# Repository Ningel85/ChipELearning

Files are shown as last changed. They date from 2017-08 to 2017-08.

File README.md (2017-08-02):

# ChipELearning
Projet ChipELearning

* Download & Install Arduino IDE: https://www.arduino.cc/en/Main/Software 
* Download & Install Teensy Driver : https://www.pjrc.com/teensy/td_download.html
* Copy all libraries to C:\Users\user\Documents\Arduino\libraries (or wherever your library folder is installed)
* Arduino IDE : "Board: Teensy 3.2" 

ChipELearning is a robot able to learn movements, which makes every ChipELearning unique !

Bill of material :
* 1 x [Teensy 3.2](http://www.francerobotique.com/electronique/457-module-teensy-32.html) 
* 1 x Teensy Shield	
* 1 x [Maestro Micro](http://www.francerobotique.com/contr%C3%B4leurs-interfaces/138-contr%C3%B4leur-usb-micro-maestro-6.html)	
* 2 x [Servomotor FeedBack Small](https://www.adafruit.com/product/1449)	
* 4 x [Servomotor FeedBack Medium](https://www.adafruit.com/product/1404)
* 1 x [Accelerometer LSM303D](http://www.francerobotique.com/orientation/244-acc%C3%A9l%C3%A9rom%C3%A8tre-3d-lsm303d.html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)	
* 1 x [IR sensor TSOP38238](http://www.francerobotique.com/luminosit%C3%A9-couleur/420-r%C3%A9cepteur-ir-tsop38238.html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)	
* 1 x [Remote control](http://www.francerobotique.com/t%C3%A9l%C3%A9commande/426-mini-t%C3%A9l%C3%A9commande.html)	
* 1 x [I2C display 128x32](https://www.adafruit.com/product/931)	
* 1 x [Regulator step-down 5V/3A](https://www.adafruit.com/product/1385)	
* 2 x [Battery 1S](http://www.francerobotique.com/batterie/302-batterie-li-ion-37v-1300mah-lb-040.html)	
* 2 x [Battery Charger](http://www.francerobotique.com/chargeur/303-chargeur-de-batterie-li-ion-lbb-040.html)

- The Teensy controller has various I/Os : I²C, UART, CAN, Touch, ADC, PWM.
It has an EEPROM big enough for the robot and is smaller than Arduino Uno and Arduino Mega.
- The Infrared sensor allows me to control the robot with a remote controller.
- The display is small but still has a decent resolution to write text and display drawings, logos, etc. Wiring the display is very simple as it uses an I²C bus to communicate.
- Touch I/Os from the Teensy board allows me to interact with the robot without the use of a push button. On ChipELearning, there is a paper fastener but anything else that conducts electricity is suitable.
- Servomotors send back their position, which allows the robot to memorize sequences of movements and play them back indefinitely.
- The accelerometer is used for the "Balance" mode. But it could also detect when it's falling or if it is upside down.
- The robot is powered by 2 Robotis batteries made of one cell each, connected in series. They could be replaced by any power supply up to 16V.
A power adapter allows to generate a 5V supply for the Teensy controller and the servos.

Functionalities :
- Remote Controller :
ChipELearning can be controlled using a remote controller.
- Walking/Motions :
The robot can move forwards, backwards and can rotate. 3 sequences of movements are predefined, and binded to keys 1, 2 and 3.
- Motion learning :
Motion learning allows the robot to do anything. Jumping, Skateboarding, etc. This feature makes any robot unique.
- Balance :
The robot keeps it's balance on it's foot.

Programme TeensyChipE V1.0  TeensyChipE.ino

=================================================================
==============================================================================

ChipELearning est un robot capable d'apprendre des mouvements ce qui rend chaque ChipELearning unique! 

Bill of material :
* 1 x [Teensy 3.2](http://www.francerobotique.com/electronique/457-module-teensy-32.html) 
* 1 x Teensy Shield	
* 1 x [Maestro Micro](http://www.francerobotique.com/contr%C3%B4leurs-interfaces/138-contr%C3%B4leur-usb-micro-maestro-6.html)	
* 2 x [Servomotor FeedBack Small](https://www.adafruit.com/product/1449)	
* 4 x [Servomotor FeedBack Medium](https://www.adafruit.com/product/1404)
* 1 x [Accelerometer LSM303D](http://www.francerobotique.com/orientation/244-acc%C3%A9l%C3%A9rom%C3%A8tre-3d-lsm303d.html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)	
* 1 x [IR sensor TSOP38238](http://www.francerobotique.com/luminosit%C3%A9-couleur/420-r%C3%A9cepteur-ir-tsop38238.html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)	
* 1 x [Remote control](http://www.francerobotique.com/t%C3%A9l%C3%A9commande/426-mini-t%C3%A9l%C3%A9commande.html)	
* 1 x [I2C display 128x32](https://www.adafruit.com/product/931)	
* 1 x [Regulator step-down 5V/3A](https://www.adafruit.com/product/1385)	
* 2 x [Battery 1S](http://www.francerobotique.com/batterie/302-batterie-li-ion-37v-1300mah-lb-040.html)	
* 2 x [Battery Charger](http://www.francerobotique.com/chargeur/303-chargeur-de-batterie-li-ion-lbb-040.html)

- Le contrôleur Teensy possède des entrées sorties très variées, I2C, UART, CAN, Touch, ADC, PWM, possède une EEPROM suffisante pour le robot et est plus petite que les arduino uno et mega.
- Le capteur Infrarouge me permet de contrôler le robot avec une télécommande
- L'afficheur est petit mais a une bonne résolution pour écrire beaucoup de texte et afficher des dessins, logos... Le câblage est simple et le module communique en I2C, ce qui est très facile à utiliser
- Les I/O touch de la carte Teensy me permet d’interagir avec le robot sans bouton poussoir. Sur ChipELearning, il y a une attache parisienne mais on peut y mettre tout type d'objet conducteur. 
- Le feedback des servomoteurs retourne leur information de position. Cette option permet au robot de mémoriser les séquences de mouvement pour les refaire indéfiniment.
- L'accéléromètre est utilisé pour le mode équilibre. Mais il pourrait aussi savoir si il tombe, si il est à l'envers...
- Le robot est alimenté par 2 batteries Robotis d'une cellule chacune. Elles sont branchées en série. Un régulateur permet d'abaisser la tension à 5V pour le contrôleur Teensy et les servomoteurs. On peut y connecter une batterie de 16V maximum.

Fonctionnalités:
- Télécommande
ChipELearning peut-être contrôlé grâce à une télécommande. Avec les flèches directionnelles, des modes de jeux et d'apprentissage ainsi que 9 mouvements.
- Déplacement/Mouvement
Le robot peut se déplacer en avant, en arrière et tourner sur lui même. 3 séquences de mouvements sont pré-enregistrées et associées aux touches 1, 2 et 3.
- Apprentissage de mouvement
L'apprentissage des mouvements permet au robot de réaliser n'importe quelle action. Sauter, Faire du skate... Cette fonction rend le robot unique!
- Équilibre
Le robot reste en équilibre sur son pied. Exemple d'utilisation de l'accéléromètre

Programme TeensyChipE V1.0  TeensyChipE.ino

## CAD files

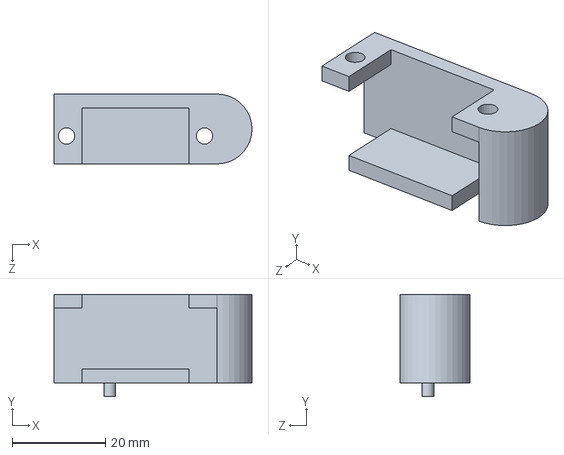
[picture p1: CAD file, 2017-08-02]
ChipE3D/MainG.SLDPRT
42.5 x 22.0 x 15.0 mm

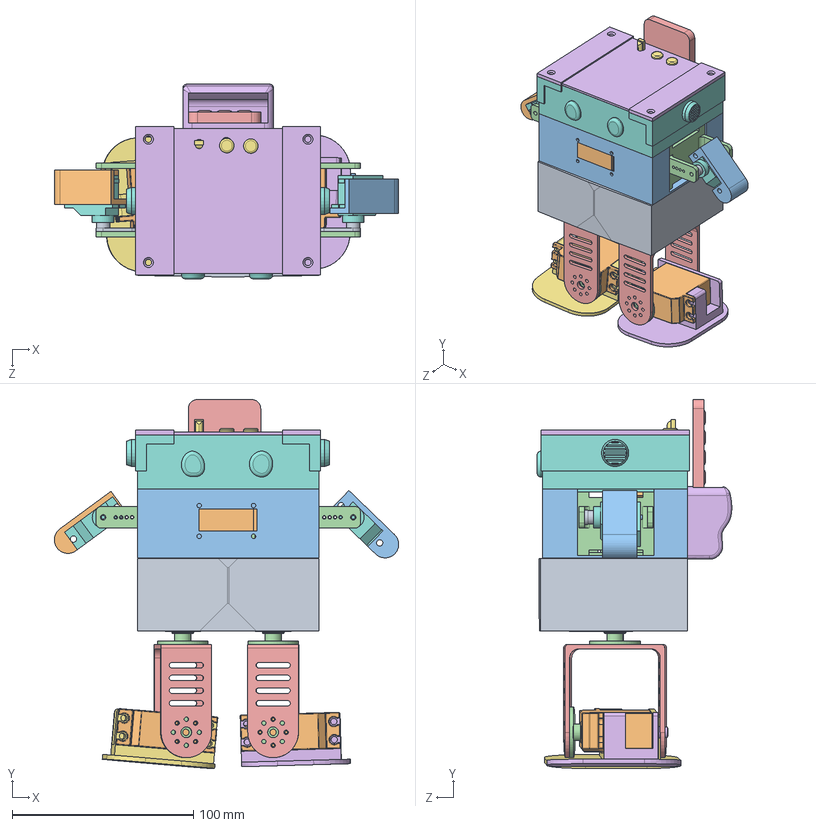
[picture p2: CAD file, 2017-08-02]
ChipE3D/Assemblage1.SLDASM
190.0 x 203.6 x 107.4 mm
BodyBase
ServoS1213 x 4
LSM303D
PalonnierS1213 x 4
Bracket x 2
Pied
Pied - Copie
BodyMiddle
SocleBat x 2
Ecran
BodyTop
Teensy-bras-corps-base-X4
PololuMicroMeastro
Couvercle
AttacheP x 2
ServoS1123 x 2
PalonnierS1123 x 2
MainD
MainG
epaule x 2
telecommande
sac
ReceptIR

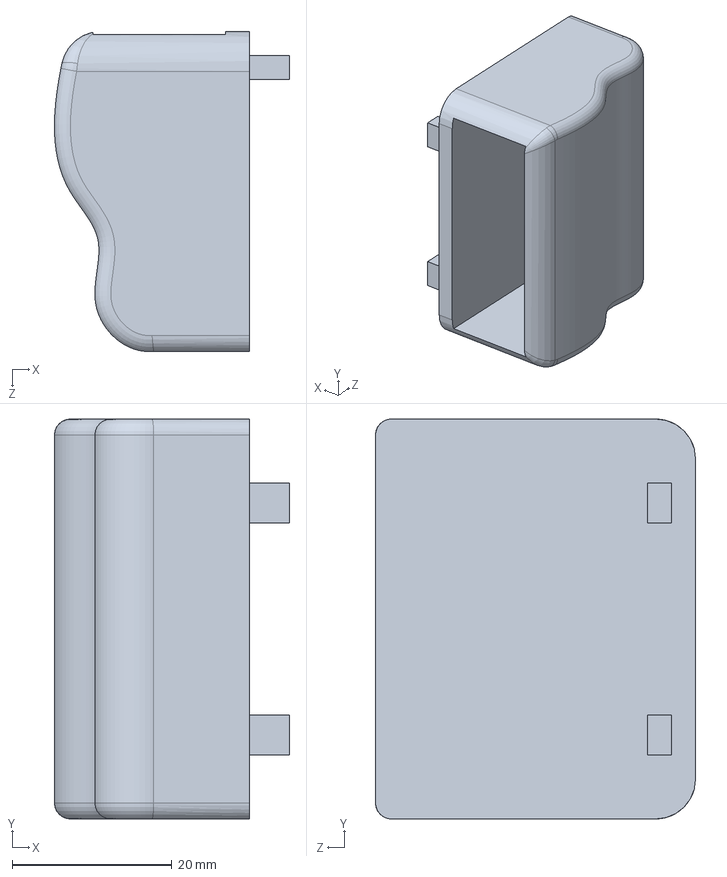
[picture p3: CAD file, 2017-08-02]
ChipE3D/sac.SLDPRT
29.4 x 50.0 x 40.0 mm

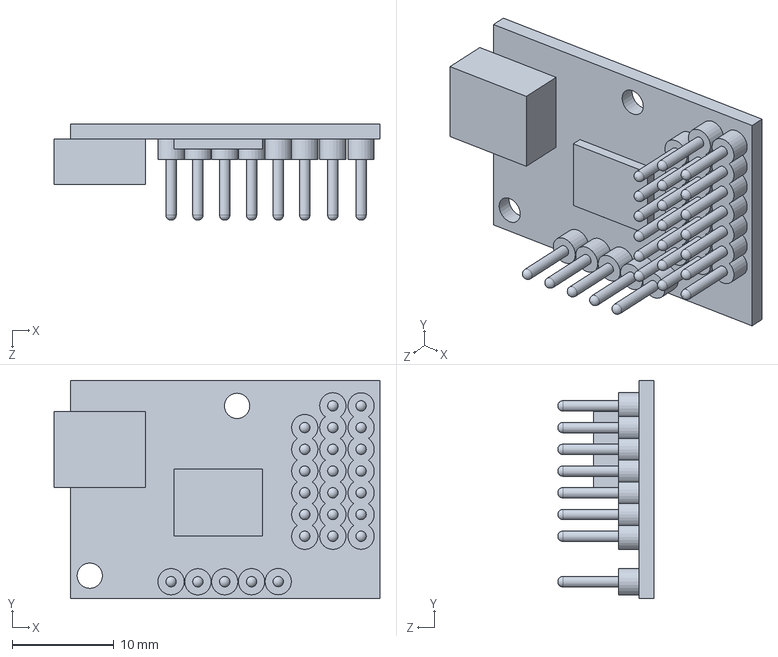
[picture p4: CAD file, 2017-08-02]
ChipE3D/PololuMicroMeastro.SLDPRT
32.1 x 21.5 x 9.50 mm

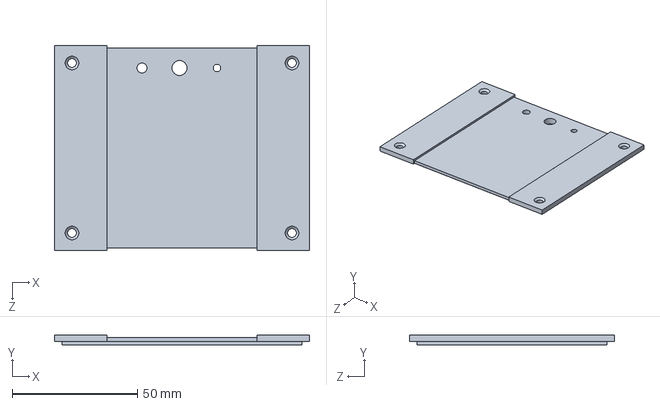
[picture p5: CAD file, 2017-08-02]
ChipE3D/Couvercle.SLDPRT
102.0 x 4.00 x 82.0 mm

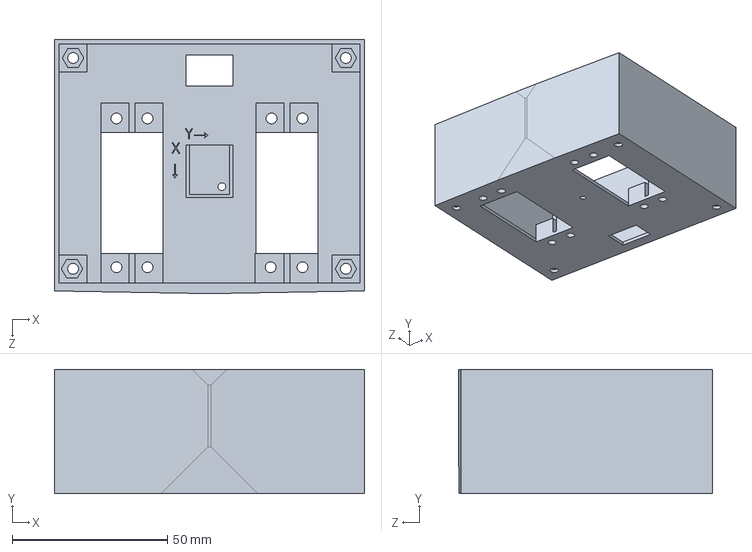
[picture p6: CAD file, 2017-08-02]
ChipE3D/BodyBase.SLDPRT
100.0 x 40.0 x 82.0 mm

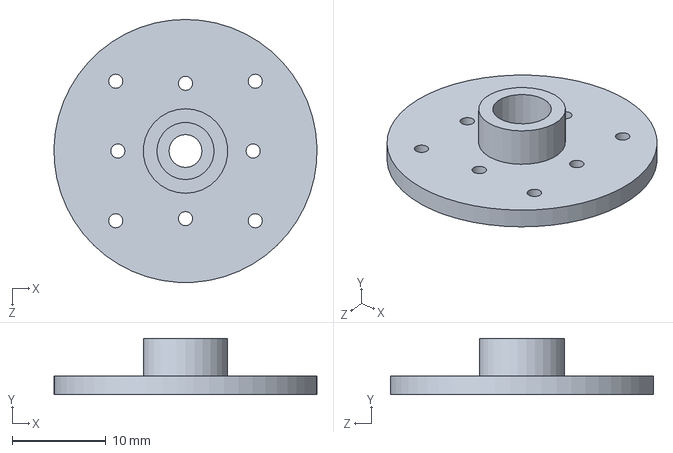
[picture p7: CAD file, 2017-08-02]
ChipE3D/PalonnierS1213.SLDPRT
28.0 x 6.00 x 28.0 mm

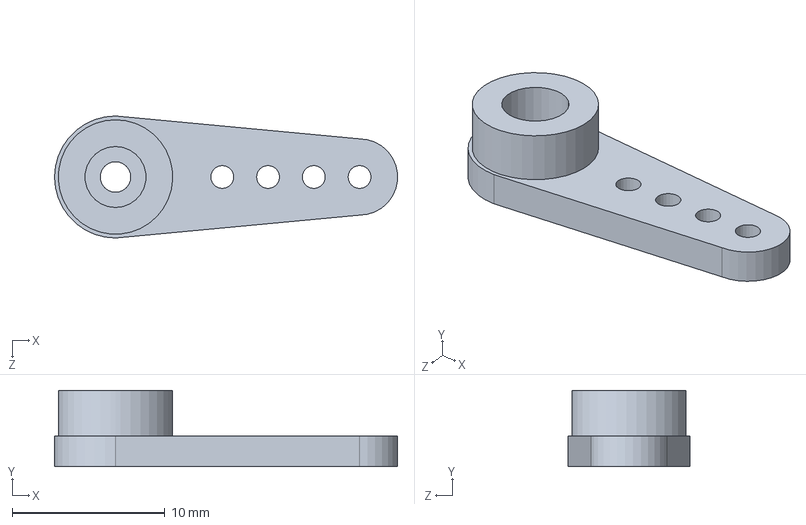
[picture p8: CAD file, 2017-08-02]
ChipE3D/PalonnierS1123.SLDPRT
22.5 x 5.00 x 8.00 mm

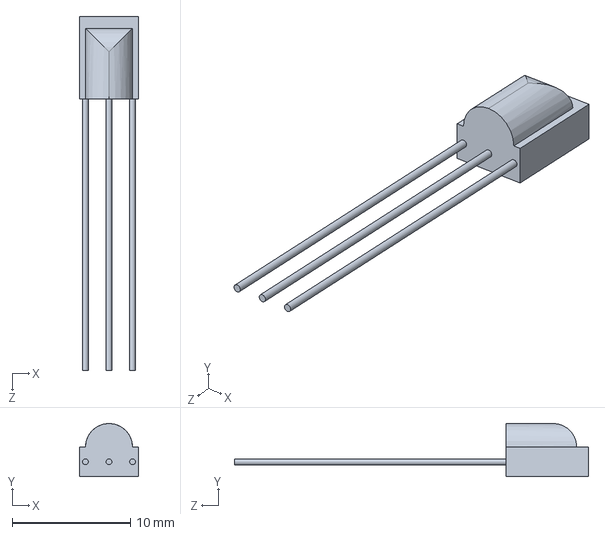
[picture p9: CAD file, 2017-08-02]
ChipE3D/ReceptIR.SLDPRT
5.00 x 4.50 x 30.0 mm

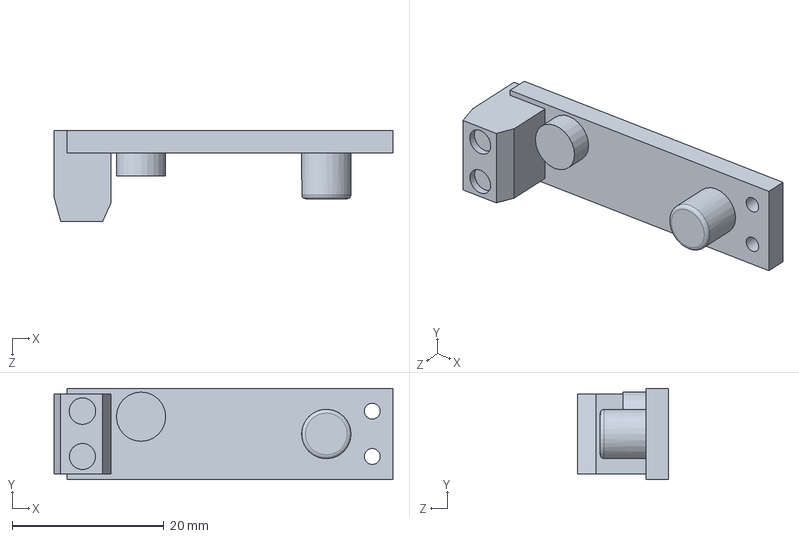
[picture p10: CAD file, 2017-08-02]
ChipE3D/Reg5VPololu3-5A.SLDPRT
44.7 x 12.0 x 12.0 mm

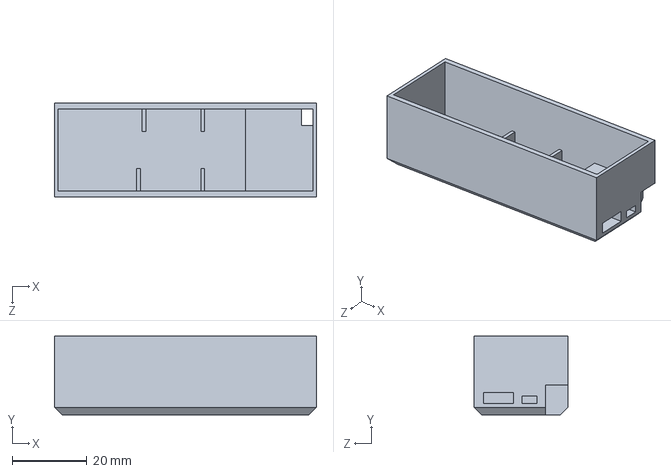
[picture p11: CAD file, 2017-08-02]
ChipE3D/SocleBat.SLDPRT
70.0 x 21.0 x 25.0 mm

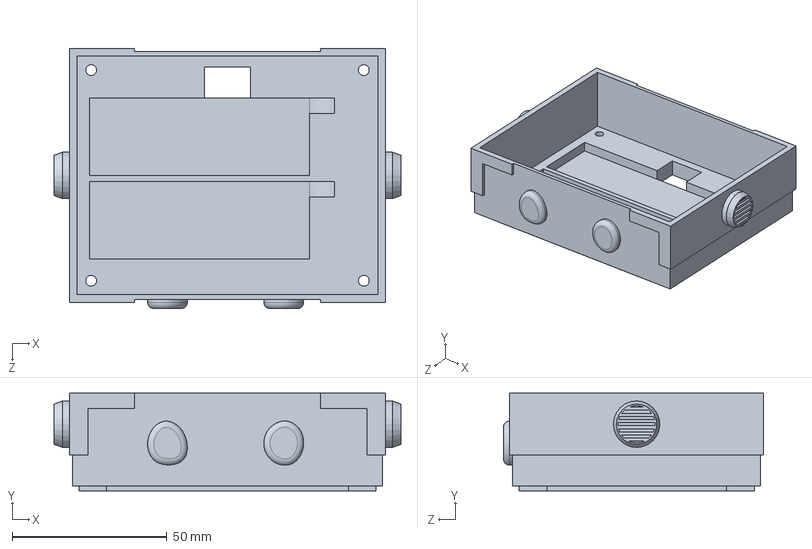
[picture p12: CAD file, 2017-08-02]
ChipE3D/BodyMiddle.SLDPRT
112.0 x 31.5 x 84.0 mm

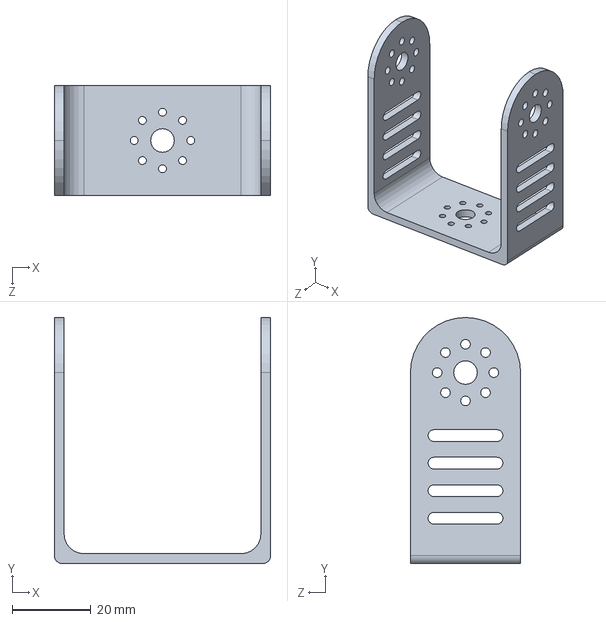
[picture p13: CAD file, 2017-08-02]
ChipE3D/Bracket.SLDPRT
55.0 x 62.5 x 28.0 mm

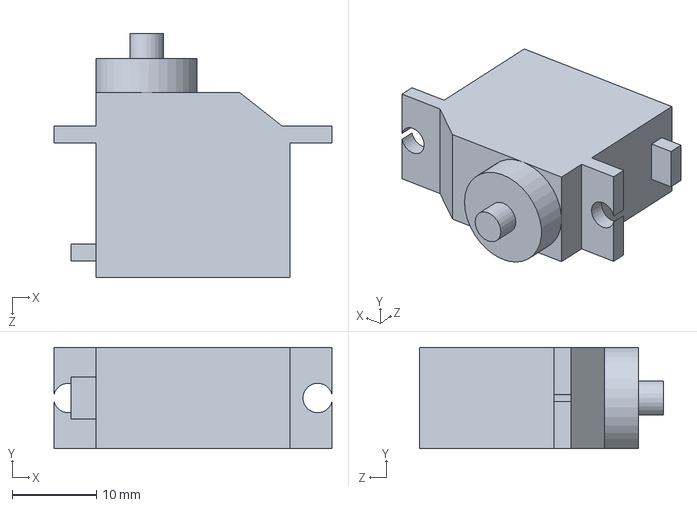
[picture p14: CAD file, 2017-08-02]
ChipE3D/ServoS1123.SLDPRT
33.0 x 12.0 x 29.0 mm

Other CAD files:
ChipE3D/MainD.SLDPRT
ChipE3D/AttacheP.SLDPRT
ChipE3D/LSM303D.SLDPRT
ChipE3D/Pied.SLDPRT
ChipE3D/BodyBase.STL
ChipE3D/BodyMiddle.STL
ChipE3D/BodyTop.SLDPRT
ChipE3D/BodyTop.STL
ChipE3D/Bracket.STL
ChipE3D/Couvercle.STL
ChipE3D/Ecran.SLDPRT
ChipE3D/MainD.STL
ChipE3D/MainG.STL
ChipE3D/Pied - Copie.SLDPRT
ChipE3D/Pied - Copie.STL
ChipE3D/Pied.STL
ChipE3D/ServoS1213.SLDPRT
ChipE3D/Teensy-bras-corps-base-X4.SLDPRT
ChipE3D/epaule.SLDPRT
ChipE3D/epaule.STL
ChipE3D/sac.STL
ChipE3D/telecommande.SLDPRT

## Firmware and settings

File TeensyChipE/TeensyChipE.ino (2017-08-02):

/*
 * ChipELearning
 * Programme pour Teensy 3.2
 * Martineau Sébastien
 * Instagram : @sebmar89
 * 10/07/2017   V1.0
 */
// Standard
#include <SPI.h>
//#include <Wire.h>

//I2C
#include <I2CTrame.h>
I2CTrame I2C_trame = I2CTrame();

//maestro 
#include <PololuMaestro.h>
#include <SoftwareSerial.h>
SoftwareSerial maestroSerial(9, 10);
MicroMaestro maestro(maestroSerial);

//acc/gyro
#include <LSM303.h>
LSM303 compass;

//touch
#include <CapacitiveSensor.h>
CapacitiveSensor TouchSensor = CapacitiveSensor(A2,A3);   // 1M   ,  1K

// EEPROM
#include <EEPROM.h>
unsigned int addr = 0;

// Display I2C
#include <Adafruit_GFX.h>
#include <Adafruit_SSD1306.h>
#define OLED_RESET 3
Adafruit_SSD1306 display(OLED_RESET);
#define NUMFLAKES 10
#define XPOS 0
#define YPOS 1
#define DELTAY 2
#define LOGO16_GLCD_HEIGHT 64 
#define LOGO16_GLCD_WIDTH  16 


// Remote control
#include <IRremote.h>
#define FLECHEH 0xFDA05F
#define FLECHEB 0xFDB04F
#define FLECHEG 0xFD10EF
#define FLECHED 0xFD50AF
#define TCH1 0xFD08F7
#define TCH2 0xFD8877
#define TCH3 0xFD48B7
#define TCH4 0xFD28D7
#define TCH5 0xFDA857
#define TCH6 0xFD6897
#define TCH7 0xFD18E7
#define TCH8 0xFD9867
#define TCH9 0xFD58A7
#define TCH0 0xFD30CF
#define VOLP 0xFD40BF
#define VOLM 0xFD00FF
#define PAUSE 0xFD807F
#define SETUP 0xFD20DF
#define MODE 0xFD609F
#define ENTER 0xFD906F
#define RETOUR 0xFD708F
int RECV_PIN = 11;
IRrecv irrecv(RECV_PIN);
decode_results results;


// Analog
int ServoM1 = A0,ServoM2 = A1,ServoM3 = A6,ServoM4 = A7,ServoM5= A8,ServoM6 = A9;    // select the input pin for the potentiometer
int sensorValue = 0;  // variable to store the value coming from the sensor

//led
#define led 13


//variable
#define _TPS 2000  // delay before screensaver
int tps =0;
int Vitesse = 500;
int INITSM0 = 6176 ,INITSM1 = 5864,INITSM2 = 6176,INITSM3 = 5864,INITSM4 = 5720,INITSM5 = 5480;
bool State_Pause = false;
bool state_remote = false;
bool state_touch = false;
bool Phase_init = false;
byte inc_nbr_position = 0;
int val_int;  
byte val_byte[11][7];
byte remote_touch;
byte pos_byte =0;
int pos_int = 0;
int data_acc_y =0;
byte V_Nominale = 15;

void setup()
{
//servomotor
  maestroSerial.begin(115200);
// led
  pinMode(led, OUTPUT);
  digitalWrite(led,HIGH);
// I2C
  I2C_trame.begin(); 
//analog  
  analogReference(DEFAULT) ;
// Remote control
  irrecv.enableIRIn(); // Start the receiver
// touch sensor
  TouchSensor.set_CS_AutocaL_Millis(0xFFFFFFFF);
  delay(200);
//acc/gyro
  compass.init();
  compass.enableDefault();
//Display 
  display.begin(SSD1306_SWITCHCAPVCC, 0x3C);  // initialize with the I2C addr 0x3C (for the 128x32)
  display.display(); // show splashscreen
  delay(2000);

// init
  display.drawSinus();
  maestro.setTarget(0, INITSM0); //6000->1500     (/4)
  maestro.setTarget(1, INITSM1);
  maestro.setTarget(2, INITSM2);
  maestro.setTarget(3, INITSM3);
  maestro.setTarget(4, INITSM4);
  maestro.setTarget(5, INITSM5);
  display.drawSinus();
  display.clearDisplay();   // clears the screen and buffer
  tps = millis();

  maestro.setSpeed(0, V_Nominale); maestro.setSpeed(1, V_Nominale); maestro.setSpeed(3, V_Nominale); maestro.setSpeed(4, V_Nominale); maestro.setSpeed(5, V_Nominale); maestro.setSpeed(6, V_Nominale); 
}

void loop() {
  
  if(millis() > (tps + _TPS)) {display.drawSinus();}
            
  if (irrecv.decode(&results)) {
    if(results.value != 0xFFFFFFFF){
            display.clearDisplay();   // clears the screen and buffer
            display.setTextSize(1);
            display.setTextColor(WHITE);
            display.setCursor(10,8);
            display.print(results.value, HEX);
            display.display(); // show 
      
            switch(results.value){
              case FLECHEH : // avance
                  State_Pause = false;
                  maestro.setTarget(0, INITSM0);  maestro.setTarget(1, INITSM1); maestro.setTarget(2, INITSM2);       maestro.setTarget(3, INITSM3);      maestro.setTarget(4, INITSM4);      maestro.setTarget(5, INITSM5);          delay(Vitesse);
                  maestro.setTarget(0, INITSM0);  maestro.setTarget(1, INITSM1); maestro.setTarget(2, INITSM2);       maestro.setTarget(3, INITSM3);      maestro.setTarget(4, INITSM4-800); maestro.setTarget(5, INITSM5-800);     delay(Vitesse);//lever
                  maestro.setTarget(0, INITSM0);  maestro.setTarget(1, INITSM1); maestro.setTarget(2, INITSM2+1000);       maestro.setTarget(3, INITSM3+1000); maestro.setTarget(4, INITSM4-800); maestro.setTarget(5, INITSM5-800);     delay(Vitesse);//tourner
                  maestro.setTarget(0, INITSM0);  maestro.setTarget(1, INITSM1); maestro.setTarget(2, INITSM2+1000);       maestro.setTarget(3, INITSM3+1000); maestro.setTarget(4, INITSM4);      maestro.setTarget(5, INITSM5);          delay(Vitesse);//baisser
                  maestro.setTarget(0, INITSM0);  maestro.setTarget(1, INITSM1); maestro.setTarget(2, INITSM2+1000);       maestro.setTarget(3, INITSM3);      maestro.setTarget(4, INITSM4+800); maestro.setTarget(5, INITSM5+800);     delay(Vitesse);//lever
                  maestro.setTarget(0, INITSM0);  maestro.setTarget(1, INITSM1); maestro.setTarget(2, INITSM2);  maestro.setTarget(3, INITSM3-1000); maestro.setTarget(4, INITSM4+800); maestro.setTarget(5, INITSM5+800);     delay(Vitesse);//tourner
                  maestro.setTarget(0, INITSM0);  maestro.setTarget(1, INITSM1); maestro.setTarget(2, INITSM2);  maestro.setTarget(3, INITSM3); maestro.setTarget(4, INITSM4);      maestro.setTarget(5, INITSM5);          delay(Vitesse);//baisser
                 
                  maestro.setTarget(0, INITSM0);  maestro.setTarget(1, INITSM1); maestro.setTarget(2, INITSM2);       maestro.setTarget(3, INITSM3);      maestro.setTarget(4, INITSM4);      maestro.setTarget(5, INITSM5);          delay(Vitesse);
                  maestro.setTarget(0, INITSM0);  maestro.setTarget(1, INITSM1); maestro.setTarget(2, INITSM2);       maestro.setTarget(3, INITSM3);      maestro.setTarget(4, INITSM4-800); maestro.setTarget(5, INITSM5-800);     delay(Vitesse);//lever
                  maestro.setTarget(0, INITSM0);  maestro.setTarget(1, INITSM1); maestro.setTarget(2, INITSM2+1000);       maestro.setTarget(3, INITSM3+1000); maestro.setTarget(4, INITSM4-800); maestro.setTarget(5, INITSM5-800);     delay(Vitesse);//tourner
                  maestro.setTarget(0, INITSM0);  maestro.setTarget(1, INITSM1); maestro.setTarget(2, INITSM2+1000);       maestro.setTarget(3, INITSM3+1000); maestro.setTarget(4, INITSM4);      maestro.setTarget(5, INITSM5);          delay(Vitesse);//baisser
                  maestro.setTarget(0, INITSM0);  maestro.setTarget(1, INITSM1); maestro.setTarget(2, INITSM2+1000);       maestro.setTarget(3, INITSM3);      maestro.setTarget(4, INITSM4+800); maestro.setTarget(5, INITSM5+800);     delay(Vitesse);//lever
                  maestro.setTarget(0, INITSM0);  maestro.setTarget(1, INITSM1); maestro.setTarget(2, INITSM2);  maestro.setTarget(3, INITSM3-1000); maestro.setTarget(4, INITSM4+800); maestro.setTarget(5, INITSM5+800);     delay(Vitesse);//tourner
                  maestro.setTarget(0, INITSM0);  maestro.setTarget(1, INITSM1); maestro.setTarget(2, INITSM2);  maestro.setTarget(3, INITSM3); maestro.setTarget(4, INITSM4);      maestro.setTarget(5, INITSM5);          delay(Vitesse);//baisser
                  
                  tps = millis();
              break;
              case FLECHEB : // recule
                  State_Pause = false;
                  
                  maestro.setTarget(0, INITSM0);  maestro.setTarget(1, INITSM1); maestro.setTarget(2, INITSM2);       maestro.setTarget(3, INITSM3);      maestro.setTarget(4, INITSM4);      maestro.setTarget(5, INITSM5);          delay(Vitesse);
                  maestro.setTarget(0, INITSM0);  maestro.setTarget(1, INITSM1); maestro.setTarget(2, INITSM2);       maestro.setTarget(3, INITSM3);      maestro.setTarget(4, INITSM4-800); maestro.setTarget(5, INITSM5-800);     delay(Vitesse);//lever
                  maestro.setTarget(0, INITSM0);  maestro.setTarget(1, INITSM1); maestro.setTarget(2, INITSM2-1000);       maestro.setTarget(3, INITSM3-1000); maestro.setTarget(4, INITSM4-800); maestro.setTarget(5, INITSM5-800);     delay(Vitesse);//tourner
                  maestro.setTarget(0, INITSM0);  maestro.setTarget(1, INITSM1); maestro.setTarget(2, INITSM2-1000);       maestro.setTarget(3, INITSM3-1000); maestro.setTarget(4, INITSM4);      maestro.setTarget(5, INITSM5);          delay(Vitesse);//baisser
                  maestro.setTarget(0, INITSM0);  maestro.setTarget(1, INITSM1); maestro.setTarget(2, INITSM2-1000);       maestro.setTarget(3, INITSM3);      maestro.setTarget(4, INITSM4+800); maestro.setTarget(5, INITSM5+800);     delay(Vitesse);//lever
                  maestro.setTarget(0, INITSM0);  maestro.setTarget(1, INITSM1); maestro.setTarget(2, INITSM2);  maestro.setTarget(3, INITSM3+1000); maestro.setTarget(4, INITSM4+800); maestro.setTarget(5, INITSM5+800);     delay(Vitesse);//tourner
                  maestro.setTarget(0, INITSM0);  maestro.setTarget(1, INITSM1); maestro.setTarget(2, INITSM2);  maestro.setTarget(3, INITSM3); maestro.setTarget(4, INITSM4);      maestro.setTarget(5, INITSM5);          delay(Vitesse);//baisser
                 
                  maestro.setTarget(0, INITSM0);  maestro.setTarget(1, INITSM1); maestro.setTarget(2, INITSM2);       maestro.setTarget(3, INITSM3);      maestro.setTarget(4, INITSM4);      maestro.setTarget(5, INITSM5);          delay(Vitesse);
                  maestro.setTarget(0, INITSM0);  maestro.setTarget(1, INITSM1); maestro.setTarget(2, INITSM2);       maestro.setTarget(3, INITSM3);      maestro.setTarget(4, INITSM4-800); maestro.setTarget(5, INITSM5-800);     delay(Vitesse);//lever
                  maestro.setTarget(0, INITSM0);  maestro.setTarget(1, INITSM1); maestro.setTarget(2, INITSM2-1000);       maestro.setTarget(3, INITSM3-1000); maestro.setTarget(4, INITSM4-800); maestro.setTarget(5, INITSM5-800);     delay(Vitesse);//tourner
                  maestro.setTarget(0, INITSM0);  maestro.setTarget(1, INITSM1); maestro.setTarget(2, INITSM2-1000);       maestro.setTarget(3, INITSM3-1000); maestro.setTarget(4, INITSM4);      maestro.setTarget(5, INITSM5);          delay(Vitesse);//baisser
                  maestro.setTarget(0, INITSM0);  maestro.setTarget(1, INITSM1); maestro.setTarget(2, INITSM2-1000);       maestro.setTarget(3, INITSM3);      maestro.setTarget(4, INITSM4+800); maestro.setTarget(5, INITSM5+800);     delay(Vitesse);//lever
                  maestro.setTarget(0, INITSM0);  maestro.setTarget(1, INITSM1); maestro.setTarget(2, INITSM2);  maestro.setTarget(3, INITSM3+1000); maestro.setTarget(4, INITSM4+800); maestro.setTarget(5, INITSM5+800);     delay(Vitesse);//tourner
                  maestro.setTarget(0, INITSM0);  maestro.setTarget(1, INITSM1); maestro.setTarget(2, INITSM2);  maestro.setTarget(3, INITSM3); maestro.setTarget(4, INITSM4);      maestro.setTarget(5, INITSM5);          delay(Vitesse);//baisser
                  
                  tps = millis();
              break;
              case FLECHEG : // tourne gauche
                  State_Pause = false;
                  maestro.setTarget(0, INITSM0);  maestro.setTarget(1, INITSM1); maestro.setTarget(2, INITSM2);       maestro.setTarget(3, INITSM3);      maestro.setTarget(4, INITSM4+800);      maestro.setTarget(5, INITSM5+800);          delay(Vitesse);
                  maestro.setTarget(0, INITSM0);  maestro.setTarget(1, INITSM1); maestro.setTarget(2, INITSM2-1200);       maestro.setTarget(3, INITSM3);      maestro.setTarget(4, INITSM4+800);      maestro.setTarget(5, INITSM5+800);          delay(Vitesse);
                  maestro.setTarget(0, INITSM0);  maestro.setTarget(1, INITSM1); maestro.setTarget(2, INITSM2-1200);       maestro.setTarget(3, INITSM3);      maestro.setTarget(4, INITSM4);      maestro.setTarget(5, INITSM5);          delay(Vitesse);
                  maestro.setTarget(0, INITSM0);  maestro.setTarget(1, INITSM1); maestro.setTarget(2, INITSM2-1200);       maestro.setTarget(3, INITSM3);      maestro.setTarget(4, INITSM4-800);      maestro.setTarget(5, INITSM5-800);          delay(Vitesse);
                  maestro.setTarget(0, INITSM0);  maestro.setTarget(1, INITSM1); maestro.setTarget(2, INITSM2);       maestro.setTarget(3, INITSM3);      maestro.setTarget(4, INITSM4-800);      maestro.setTarget(5, INITSM5-800);          delay(Vitesse);
                  maestro.setTarget(0, INITSM0);  maestro.setTarget(1, INITSM1); maestro.setTarget(2, INITSM2);       maestro.setTarget(3, INITSM3);      maestro.setTarget(4, INITSM4);      maestro.setTarget(5, INITSM5);          delay(Vitesse);
                  tps = millis();
              break;
              case FLECHED : // tourne droite
                  State_Pause = false;
                  maestro.setTarget(0, INITSM0);  maestro.setTarget(1, INITSM1); maestro.setTarget(2, INITSM2);       maestro.setTarget(3, INITSM3);      maestro.setTarget(4, INITSM4-800);      maestro.setTarget(5, INITSM5-800);          delay(Vitesse);
                  maestro.setTarget(0, INITSM0);  maestro.setTarget(1, INITSM1); maestro.setTarget(2, INITSM2);       maestro.setTarget(3, INITSM3+1200);      maestro.setTarget(4, INITSM4-800);      maestro.setTarget(5, INITSM5-800);          delay(Vitesse);
                  maestro.setTarget(0, INITSM0);  maestro.setTarget(1, INITSM1); maestro.setTarget(2, INITSM2);       maestro.setTarget(3, INITSM3+1200);      maestro.setTarget(4, INITSM4);      maestro.setTarget(5, INITSM5);          delay(Vitesse);
                  maestro.setTarget(0, INITSM0);  maestro.setTarget(1, INITSM1); maestro.setTarget(2, INITSM2);       maestro.setTarget(3, INITSM3+1200);      maestro.setTarget(4, INITSM4+800);      maestro.setTarget(5, INITSM5+800);          delay(Vitesse);
                  maestro.setTarget(0, INITSM0);  maestro.setTarget(1, INITSM1); maestro.setTarget(2, INITSM2);       maestro.setTarget(3, INITSM3);      maestro.setTarget(4, INITSM4+800);      maestro.setTarget(5, INITSM5+800);          delay(Vitesse);
                  maestro.setTarget(0, INITSM0);  maestro.setTarget(1, INITSM1); maestro.setTarget(2, INITSM2);       maestro.setTarget(3, INITSM3);      maestro.setTarget(4, INITSM4);      maestro.setTarget(5, INITSM5);          delay(Vitesse);
                  tps = millis();
              break;
              case MODE : // balancing
                  State_Pause = false;
                  state_remote = false;
                  state_touch = false;
                  Phase_init = false;
                  compass.read();
                  data_acc_y = compass.a.y;
                  display.clearDisplay();   // clears the screen and buffer
                  display.setTextSize(1);
                  display.setTextColor(WHITE);
                  display.setCursor(10,8);
                  display.print("Balancing");
                  display.setCursor(10,16);
                  display.print(data_acc_y);
                  display.display(); // show 
                  maestro.setSpeed(5, 5); 
                  maestro.setSpeed(4, 10);
                  maestro.setTarget(0, INITSM0);      maestro.setTarget(1, INITSM1);      maestro.setTarget(2, INITSM2);      maestro.setTarget(3, INITSM3);  maestro.setTarget(4, INITSM4-2000);  maestro.setTarget(5, INITSM5-4000);     delay(1000);
                  maestro.setTarget(0, INITSM0);      maestro.setTarget(1, INITSM1);      maestro.setTarget(2, INITSM2);      maestro.setTarget(3, INITSM3);  maestro.setTarget(4, INITSM4);  maestro.setTarget(5, INITSM5-3000);     delay(200);
                  
                  maestro.setSpeed(5, 4); 
                  do{
                     if (irrecv.decode(&results)) {
                        if(results.value != 0xFFFFFFFF &&  results.value == RETOUR ){
                            state_remote = true;
                        }
                     }
                     irrecv.resume(); // Receive the next value
                     if((TouchSensor.capacitiveSensor(50)/10) > 200){
                            state_touch = true;
                     }
                     compass.read();
                     data_acc_y = compass.a.y;
                     display.clearDisplay();   // clears the screen and buffer
                     display.setTextSize(1);
                     display.setTextColor(WHITE);
                     display.setCursor(10,8);
                     display.print("Balancing");
                     display.setCursor(10,16);
                     display.print( data_acc_y);
                     display.display(); // show 
                     
                        maestro.setTarget(5, INITSM5 + ((data_acc_y)/4) - 3000); 
                        maestro.setTarget(4, INITSM4 - ((data_acc_y)/8)); 
                        maestro.setTarget(1, INITSM1 - ((data_acc_y)/8)); 
                        maestro.setTarget(0, INITSM0 - ((data_acc_y)/8)); 
                     
                     delay(200);
                  }while(!state_remote && !state_touch);
                  maestro.setSpeed(0, V_Nominale); maestro.setSpeed(1, V_Nominale); maestro.setSpeed(3, V_Nominale); maestro.setSpeed(4, V_Nominale); maestro.setSpeed(5, V_Nominale); maestro.setSpeed(6, V_Nominale); 
                  maestro.setTarget(0, INITSM0);      maestro.setTarget(1, INITSM1);      maestro.setTarget(2, INITSM2);      maestro.setTarget(3, INITSM3);maestro.setTarget(4, INITSM4);maestro.setTarget(5, INITSM5);     delay(Vitesse);
                  tps = millis();
              break;
              case TCH0 :
                  State_Pause = false;
                  display.clearDisplay();   // clears the screen and buffer
                  display.setTextSize(1);
                  display.setTextColor(WHITE);
                  display.setCursor(10,8);
                  display.print("Position init");
                  display.display(); // show 
                  maestro.setTarget(0, INITSM0);      maestro.setTarget(1, INITSM1);      maestro.setTarget(2, INITSM2);      maestro.setTarget(3, INITSM3);maestro.setTarget(4, INITSM4);maestro.setTarget(5, INITSM5);     delay(Vitesse);
                  tps = millis();
              break;
              case TCH1 : // mvt eeprom 1
                  State_Pause = false;
                  maestro.setTarget(0, INITSM0);      maestro.setTarget(1, INITSM1);      maestro.setTarget(2, INITSM2);      maestro.setTarget(3, INITSM3);  maestro.setTarget(4, INITSM4);  maestro.setTarget(5, INITSM5);     delay(Vitesse);
                  maestro.setTarget(0, INITSM0-1000); maestro.setTarget(1, INITSM1-1000); maestro.setTarget(2, INITSM2-1000); maestro.setTarget(3, INITSM3);  maestro.setTarget(4, INITSM4);  maestro.setTarget(5, INITSM5);     delay(Vitesse);
                  maestro.setTarget(0, INITSM0);      maestro.setTarget(1, INITSM1);      maestro.setTarget(2, INITSM2);      maestro.setTarget(3, INITSM3);  maestro.setTarget(4, INITSM4);  maestro.setTarget(5, INITSM5);     delay(Vitesse);
                  maestro.setTarget(0, INITSM0-1000); maestro.setTarget(1, INITSM1-1000); maestro.setTarget(2, INITSM2-1000); maestro.setTarget(3, INITSM3);  maestro.setTarget(4, INITSM4);  maestro.setTarget(5, INITSM5);     delay(Vitesse);
                  maestro.setTarget(0, INITSM0);      maestro.setTarget(1, INITSM1);      maestro.setTarget(2, INITSM2);      maestro.setTarget(3, INITSM3);  maestro.setTarget(4, INITSM4);  maestro.setTarget(5, INITSM5);     delay(Vitesse);
                  tps = millis();
              break;
              case TCH2 : // mvt eeprom 2
                  State_Pause = false;
                  maestro.setTarget(0, INITSM0+1000);  maestro.setTarget(1, INITSM1); maestro.setTarget(2, INITSM2);       maestro.setTarget(3, INITSM3);      maestro.setTarget(4, INITSM4);      maestro.setTarget(5, INITSM5);          delay(Vitesse);
                  maestro.setTarget(0, INITSM0-1000);  maestro.setTarget(1, INITSM1); maestro.setTarget(2, INITSM2);       maestro.setTarget(3, INITSM3);      maestro.setTarget(4, INITSM4);      maestro.setTarget(5, INITSM5);          delay(Vitesse);
                  maestro.setTarget(0, INITSM0+1000);  maestro.setTarget(1, INITSM1); maestro.setTarget(2, INITSM2);       maestro.setTarget(3, INITSM3);      maestro.setTarget(4, INITSM4);      maestro.setTarget(5, INITSM5);          delay(Vitesse);
                  maestro.setTarget(0, INITSM0-1000);  maestro.setTarget(1, INITSM1); maestro.setTarget(2, INITSM2);       maestro.setTarget(3, INITSM3);      maestro.setTarget(4, INITSM4);      maestro.setTarget(5, INITSM5);          delay(Vitesse);
                  maestro.setTarget(0, INITSM0+1000);  maestro.setTarget(1, INITSM1); maestro.setTarget(2, INITSM2);       maestro.setTarget(3, INITSM3);      maestro.setTarget(4, INITSM4);      maestro.setTarget(5, INITSM5);          delay(Vitesse);
                  maestro.setTarget(0, INITSM0);       maestro.setTarget(1, INITSM1); maestro.setTarget(2, INITSM2);       maestro.setTarget(3, INITSM3);      maestro.setTarget(4, INITSM4-800);      maestro.setTarget(5, INITSM5);          delay(Vitesse);
                  
                  tps = millis();
              break;
              case TCH3 : // mvt eeprom 3
                  State_Pause = false;
                  tps = millis();
              break;
              case TCH4 : // mvt ram 4
                  State_Pause = false;
                   for(int j=1; j<11 ; j++){
                         if((EEPROM.read((4*10*7)+(j*7)))==0xFF){
                            for(int k=1; k<7 ; k++){
                                  if(k==1 || k==2){
                                    pos_byte = EEPROM.read((4*10*7)+(j*7)+k);  pos_int = map(pos_byte, 0, 180, 4000, 8000);   maestro.setTarget((k-1), pos_int);                               
                                  }else{
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

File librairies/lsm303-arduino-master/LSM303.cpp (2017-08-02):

#include <LSM303.h>
//#include <Wire.h>
#include <i2c_t3.h>
#include <math.h>

// Defines ////////////////////////////////////////////////////////////////

// The Arduino two-wire interface uses a 7-bit number for the address,
// and sets the last bit correctly based on reads and writes
#define D_SA0_HIGH_ADDRESS                0b0011101
#define D_SA0_LOW_ADDRESS                 0b0011110
#define DLHC_DLM_DLH_MAG_ADDRESS          0b0011110
#define DLHC_DLM_DLH_ACC_SA0_HIGH_ADDRESS 0b0011001
#define DLM_DLH_ACC_SA0_LOW_ADDRESS       0b0011000

#define TEST_REG_ERROR -1

#define D_WHO_ID    0x49
#define DLM_WHO_ID  0x3C

// Constructors ////////////////////////////////////////////////////////////////

LSM303::LSM303(void)
{
  /*
  These values lead to an assumed magnetometer bias of 0.
  Use the Calibrate example program to determine appropriate values
  for your particular unit. The Heading example demonstrates how to
  adjust these values in your own sketch.
  */
  m_min = (LSM303::vector<int16_t>){-32767, -32767, -32767};
  m_max = (LSM303::vector<int16_t>){+32767, +32767, +32767};

  _device = device_auto;

  io_timeout = 0;  // 0 = no timeout
  did_timeout = false;
}

// Public Methods //////////////////////////////////////////////////////////////

// Did a timeout occur in readAcc(), readMag(), or read() since the last call to timeoutOccurred()?
bool LSM303::timeoutOccurred()
{
  bool tmp = did_timeout;
  did_timeout = false;
  return tmp;
}

void LSM303::setTimeout(unsigned int timeout)
{
  io_timeout = timeout;
}

unsigned int LSM303::getTimeout()
{
  return io_timeout;
}

bool LSM303::init(deviceType device, sa0State sa0)
{
  // perform auto-detection unless device type and SA0 state were both specified
  if (device == device_auto || sa0 == sa0_auto)
  {
    // check for LSM303D if device is unidentified or was specified to be this type
    if (device == device_auto || device == device_D)
    {
      // check SA0 high address unless SA0 was specified to be low
      if (sa0 != sa0_low && testReg(D_SA0_HIGH_ADDRESS, WHO_AM_I) == D_WHO_ID)
      {
        // device responds to address 0011101 with D ID; it's a D with SA0 high
        device = device_D;
        sa0 = sa0_high;
      }
      // check SA0 low address unless SA0 was specified to be high
      else if (sa0 != sa0_high && testReg(D_SA0_LOW_ADDRESS, WHO_AM_I) == D_WHO_ID)
      {
        // device responds to address 0011110 with D ID; it's a D with SA0 low
        device = device_D;
        sa0 = sa0_low;
      }
    }
    
    // check for LSM303DLHC, DLM, DLH if device is still unidentified or was specified to be one of these types
    if (device == device_auto || device == device_DLHC || device == device_DLM || device == device_DLH)
    {
      // check SA0 high address unless SA0 was specified to be low
      if (sa0 != sa0_low && testReg(DLHC_DLM_DLH_ACC_SA0_HIGH_ADDRESS, CTRL_REG1_A) != TEST_REG_ERROR)
      {
        // device responds to address 0011001; it's a DLHC, DLM with SA0 high, or DLH with SA0 high
        sa0 = sa0_high;
        if (device == device_auto)
        { 
          // use magnetometer WHO_AM_I register to determine device type
          //
          // DLHC seems to respond to WHO_AM_I request the same way as DLM, even though this
          // register isn't documented in its datasheet. Since the DLHC accelerometer address is the
          // same as the DLM with SA0 high, but Pololu DLM boards pull SA0 low by default, we'll
          // guess that a device whose accelerometer responds to the SA0 high address and whose
          // magnetometer gives the DLM ID is actually a DLHC.
          device = (testReg(DLHC_DLM_DLH_MAG_ADDRESS, WHO_AM_I_M) == DLM_WHO_ID) ? device_DLHC : device_DLH;
        }
      }
      // check SA0 low address unless SA0 was specified to be high
      else if (sa0 != sa0_high && testReg(DLM_DLH_ACC_SA0_LOW_ADDRESS, CTRL_REG1_A) != TEST_REG_ERROR)
      {
        // device responds to address 0011000; it's a DLM with SA0 low or DLH with SA0 low
        sa0 = sa0_low;
        if (device == device_auto)
        {
          // use magnetometer WHO_AM_I register to determine device type
          device = (testReg(DLHC_DLM_DLH_MAG_ADDRESS, WHO_AM_I_M) == DLM_WHO_ID) ? device_DLM : device_DLH;
        }
      }
    }
    
    // make sure device and SA0 were successfully detected; otherwise, indicate failure
    if (device == device_auto || sa0 == sa0_auto)
    {
      return false;
    }
  }
  
  _device = device;
  
  // set device addresses and translated register addresses
  switch (device)
  {
    case device_D:
      acc_address = mag_address = (sa0 == sa0_high) ? D_SA0_HIGH_ADDRESS : D_SA0_LOW_ADDRESS;
      translated_regs[-OUT_X_L_M] = D_OUT_X_L_M;
      translated_regs[-OUT_X_H_M] = D_OUT_X_H_M;
      translated_regs[-OUT_Y_L_M] = D_OUT_Y_L_M;
      translated_regs[-OUT_Y_H_M] = D_OUT_Y_H_M;
      translated_regs[-OUT_Z_L_M] = D_OUT_Z_L_M;
      translated_regs[-OUT_Z_H_M] = D_OUT_Z_H_M;
      break;

    case device_DLHC:
      acc_address = DLHC_DLM_DLH_ACC_SA0_HIGH_ADDRESS; // DLHC doesn't have configurable SA0 but uses same acc address as DLM/DLH with SA0 high
      mag_address = DLHC_DLM_DLH_MAG_ADDRESS;
      translated_regs[-OUT_X_H_M] = DLHC_OUT_X_H_M;
      translated_regs[-OUT_X_L_M] = DLHC_OUT_X_L_M;
      translated_regs[-OUT_Y_H_M] = DLHC_OUT_Y_H_M;
      translated_regs[-OUT_Y_L_M] = DLHC_OUT_Y_L_M;
      translated_regs[-OUT_Z_H_M] = DLHC_OUT_Z_H_M;
      translated_regs[-OUT_Z_L_M] = DLHC_OUT_Z_L_M;
      break;

    case device_DLM:
      acc_address = (sa0 == sa0_high) ? DLHC_DLM_DLH_ACC_SA0_HIGH_ADDRESS : DLM_DLH_ACC_SA0_LOW_ADDRESS;
      mag_address = DLHC_DLM_DLH_MAG_ADDRESS;
      translated_regs[-OUT_X_H_M] = DLM_OUT_X_H_M;
      translated_regs[-OUT_X_L_M] = DLM_OUT_X_L_M;
      translated_regs[-OUT_Y_H_M] = DLM_OUT_Y_H_M;
      translated_regs[-OUT_Y_L_M] = DLM_OUT_Y_L_M;
      translated_regs[-OUT_Z_H_M] = DLM_OUT_Z_H_M;
      translated_regs[-OUT_Z_L_M] = DLM_OUT_Z_L_M;
      break;

    case device_DLH:
      acc_address = (sa0 == sa0_high) ? DLHC_DLM_DLH_ACC_SA0_HIGH_ADDRESS : DLM_DLH_ACC_SA0_LOW_ADDRESS;
      mag_address = DLHC_DLM_DLH_MAG_ADDRESS;
      translated_regs[-OUT_X_H_M] = DLH_OUT_X_H_M;
      translated_regs[-OUT_X_L_M] = DLH_OUT_X_L_M;
      translated_regs[-OUT_Y_H_M] = DLH_OUT_Y_H_M;
      translated_regs[-OUT_Y_L_M] = DLH_OUT_Y_L_M;
      translated_regs[-OUT_Z_H_M] = DLH_OUT_Z_H_M;
      translated_regs[-OUT_Z_L_M] = DLH_OUT_Z_L_M;
      break;
  }
  
  return true;
}
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

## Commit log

2017-08-02 Commit TeensyChipE.ino
2017-08-02 Commit ChipELearning 3D
    [Assemblage1.SLDASM, AttacheP.SLDPRT, BodyBase.SLDPRT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]
